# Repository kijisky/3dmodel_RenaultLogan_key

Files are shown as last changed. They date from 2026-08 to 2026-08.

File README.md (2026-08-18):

# Renault Logan key — parametric CAD model

A clean, printable **two-piece (clamshell) key head** for a Renault / Dacia
Logan, built **from scratch** as a parametric B-rep model in
[CadQuery](https://cadquery.readthedocs.io/) (OpenCASCADE kernel). Editing the
parameters at the top of the script reflows the whole part and re-exports
print-ready STLs.

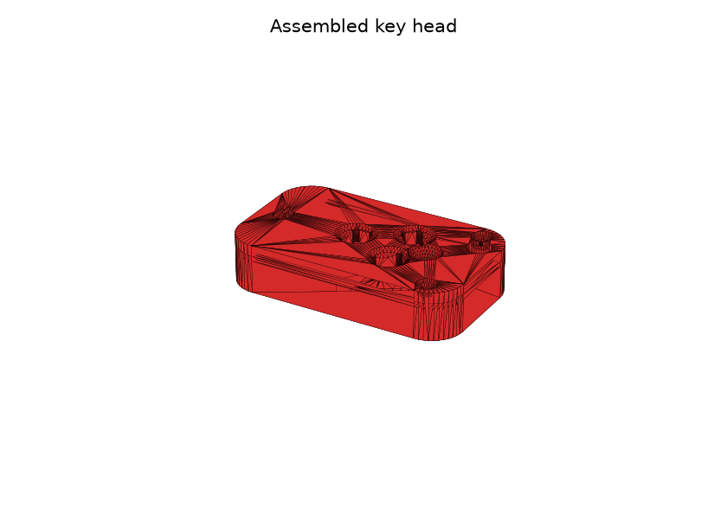
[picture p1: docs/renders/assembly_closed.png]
assembled
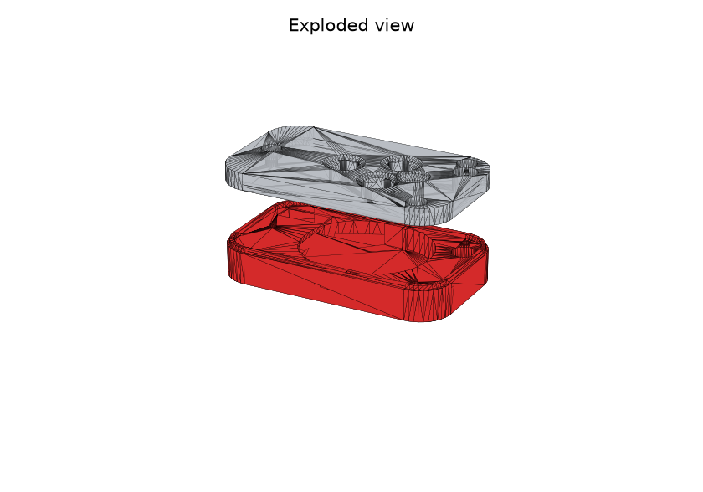
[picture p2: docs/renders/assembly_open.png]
exploded
|  |  |
|---|---|
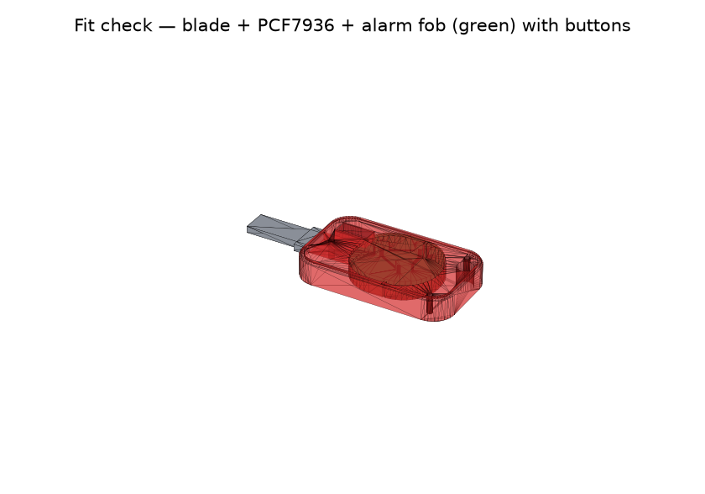
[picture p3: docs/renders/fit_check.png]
fit check
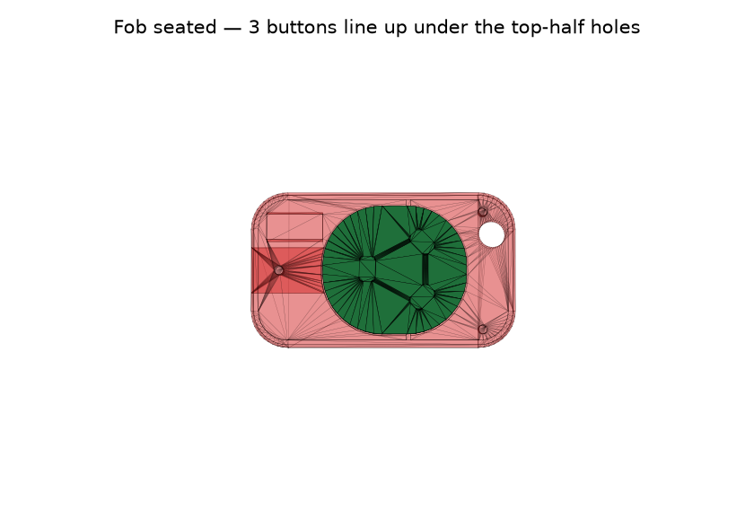
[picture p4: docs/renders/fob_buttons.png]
fob + buttons
|  |  |

> The gray blade, dark chip and green fob in the *fit-check* views are
> **reference geometry only** — they are not part of any printed STL.

Head envelope ≈ **58 × 34 × 12 mm** (auto-sized around the fob, with extra rear
body for the keyring hole). The parting plane is NOT at the mid-height: the
**bottom is thicker, the top (lid) thinner** (`split_ratio`, default 65/35), so
most of the fob and all of the blade/chip retention features sit in the
sturdier half.

## What it holds

1. **Alarm-remote fob** — a round PCB **31.5 × 28 mm, ~7 mm thick, 3 buttons on
   one face** — drops into a rounded **cavity** that fills the middle and rear
   of the head. **Retainer ribs** on the cavity walls grip its edge so it can't
   rattle or spin. Three **rectangular button openings** through the **top** half
   sit over the buttons — each opening is **rotated** (radial from the fob
   centre by default, matching the angled button layout seen on the board) so
   the caps drop in squarely; they're pressed with the lid closed. Insert the
   fob with the shell open, then close the lid.

2. **Blade inserts from the front, like the OEM key, and holds without the
   second half.** The flat metal **tang** slides into a slot in the solid front
   of the **bottom** half; the wider **shoulder** butts the front face as the
   depth stop. Floor + a thin **cap** + side walls capture the tang, and a
   **bolt** through the tang's factory hole locks pull-out (and clamps the two
   halves at the front). The slot runs **through into the fob cavity** (10 mm
   wide), so it is a passage — print supports push straight out into the
   interior instead of being trapped in a blind pocket.

3. **Immobilizer** — the **PCF7936 / "ID46"** transponder sits in a small nest
   in the solid front, right next to the blade, molded **entirely into the
   bottom half**. The nest is full width down low, then **narrows into an
   overhanging snap lip** just below the parting plane: press the chip down
   past the lip (the thin wall flexes briefly) and it springs back over the
   chip — so the chip is **captive in the bottom half alone**, even with the
   top half off. A hold-down pad on the lid adds a second retention layer once
   the key is closed.

4. **Keyring hole** — a plain hole through the extra solid body behind the fob
   (the body is simply longer; no protruding loop). Two back-corner assembly
   screws and an alignment lip/groove close the clamshell.

Because the enlarged front of the head is solid, the blade dock / chip nest /
keyring / bolt are just pockets cut into it — no separate printed bosses.

## Files

```
cad/renault_logan_key.py             the parametric model (edit this — CadQuery)
cad/renault_logan_key_freecad.FCMacro same model as a LIVE FreeCAD parametric object (edit in the GUI)
cad/render_previews.py               regenerates docs/renders/*.png from the STLs
export/bottom_shell.stl              print-ready, flat-side down          (+ .step)
export/top_shell.stl                 print-ready, flat-side down          (+ .step)
export/key_assembled.stl             both halves fused (visual check)     (+ .step)
docs/renders/*.png                   preview images
requirements.txt                     cadquery + render deps
```

Both shell STLs are clean, watertight 2-manifold solids (verified: 0 boundary
edges, 0 non-manifold junctions) and print **flat-side down with no supports**.

## How the blade is held (cross-sections)

```
 side view (Y=0)                       top view (blade height)
 +--------- cap -----------+           front face
 |####  +- tang slot ------|--> into    |  +- 10 mm slot ---------|--> fob
 |####  |   BLADE ---->    | fob cavity  |  |  (through)          | cavity
 |#### bolt  +------------ |             |  +--------------------- |
 |####  # solid / thread # |  shoulder --+<-- butts the front face (depth stop)
 +-- floor ----------------+           bolt hole (o)  through the tang
```

Front insertion: the tang slides in until the **shoulder hits the front
face**. The **bolt** drops through the tang's hole into the solid front and
locks it against pulling back out.

## Build / export

```bash
pip install -r requirements.txt

# export the three STLs into export/
python3 cad/renault_logan_key.py

# also write STEP files (for editing in other CAD)
python3 cad/renault_logan_key.py --step

# regenerate the preview PNGs
python3 cad/render_previews.py
```

## Opening / editing in FreeCAD

Two options depending on what you need:

- **Just want the geometry in FreeCAD?** Import `export/*.step` (File → Import)
  — exact geometry, one click, but a static shape (no parameters, no tree).
- **Want to tweak dimensions directly in FreeCAD's own GUI, no code editing?**
  Run `cad/renault_logan_key_freecad.FCMacro`:
  ```bash
  freecadcmd cad/renault_logan_key_freecad.FCMacro      # headless, no GUI needed
  # or, inside FreeCAD: Macro -> Macros... -> Execute -> browse to the file
  ```
  This builds a **live parametric model** using FreeCAD's own scripted-object
  mechanism (`Part::FeaturePython`), not just a one-shot static shape:

  - A **`KeyParameters`** object appears in the model tree holding every
    dimension (head size, blade, fob, buttons, immobilizer, keyring, screws,
    fit) as an ordinary FreeCAD Property, grouped in the Property panel.
  - **`BottomShell`**, **`TopShell`**, **`KeyAssembled`** (plus reference
    `RefBlade` / `RefChip` / `RefFob`) all read from `KeyParameters` and
    rebuild their shape on recompute.

  **To change something:** select `KeyParameters` in the tree, edit any value
  in the Property panel (e.g. `head_length`, `chip_snap_overlap`,
  `button_x`/`button_y`), then **recompute** (the refresh-arrows toolbar
  button, or F5) — `BottomShell`/`TopShell`/`KeyAssembled` all update
  automatically. Export whichever one you want via File → Export (STL for
  printing, STEP for elsewhere) once you're happy with it. No code, no
  re-running the macro needed for ordinary tweaks.

  Re-running the macro later (e.g. in a fresh FreeCAD session after reopening
  the file) is safe — it reuses the existing objects and just re-attaches
  their live-recompute behaviour, **without discarding any values you already
  edited**; it only fills in the defaults below the very first time.

  ### On this port's verification
  This dev environment has no FreeCAD install, so the macro could not be run
  inside real FreeCAD. It **was** verified by executing the identical
  Part-API call sequence (same `Part.makeBox` / `makeCylinder` / `fuse` /
  `cut` / `makeFillet` calls) directly against the OpenCASCADE kernel that
  FreeCAD's own `Part` module wraps, including the full live-editing cycle:
  build → edit a property → confirm the shape is still the OLD size →
  recompute → confirm it changed to the NEW size → re-run the macro →
  confirm the edited value survived and no objects were duplicated. Bounding
  boxes and **exact BREP volumes matched the CadQuery model to 0.1 mm³**, and
  every resulting mesh was watertight (0 boundary edges, 0 non-manifold
  junctions) both at the default dimensions and after editing several
  parameters at once. The one thing that couldn't be exercised from outside
  FreeCAD is the literal `FreeCAD`/`Part` module surface and the Property
  panel UI itself (`addProperty`'s exact runtime behaviour, `.FCStd`
  save/reload of the scripted Proxy) — if something looks off there on first
  run, the geometry underneath it is already proven correct; it would be a
  FreeCAD-API detail to adjust, not a design problem.

## IMPORTANT — measure your own blank before printing

There is no verified physical Logan blank behind these numbers, so the
blade/shoulder dimensions are **estimates** for the Renault/Dacia
**NE73 / VA2 / VAC102** blade family and the PCF7936 nest is sized from the
common aftermarket "ID46" carrier. Clones vary. Put calipers on your actual
parts and update the `KeyParams` block at the top of
`cad/renault_logan_key.py`:

```python
fob_length, fob_width, fob_body_thickness    # your alarm fob PCB (31.5 x 28 x 7)
fob_button_height                            # how far the buttons stand proud
button_positions                             # (x, y) of each button in FOB-LOCAL mm
button_slot_l, button_slot_w                 # rectangular opening size  << CHECK THESE
button_radial, button_angles                 # opening rotation — see below
indicator_x, indicator_y                     # blink-LED dish centre, FOB-LOCAL mm  << CHECK THESE
blade_width, blade_thickness, blade_insert   # the tang that enters the head
shoulder_width, shoulder_length              # the external stop (width > blade_width)
bolt_offset                                  # must line up with the hole in YOUR tang
chip_length, chip_width, chip_thickness      # your PCF7936 carrier
chip_snap_lip_height, chip_snap_overlap      # how strong the chip's snap retention is
split_ratio                                  # bottom/top thickness split (0.5 = even)
clearance                                    # loosen/tighten every pocket at once
```

`button_positions` came from the supplied photos and **must be verified** against
your board — they set where the top-half holes land. Each opening is rotated by
`button_radial` (default: auto — points radially away from the fob centre,
matching the angled layout in the photos); set `button_radial = False` and fill
in `button_angles` (degrees per button) if you need exact angles instead. The
head envelope (`head_length/width/height`) is chosen to wrap the fob; if you
change the fob size, bump these to keep ~2 mm of wall around it.

`indicator_x`/`indicator_y` place the dished-down spot over the fob's blink
LED (between the two side buttons by default) — verify against your board.
It isn't a hole: `indicator_dimple_depth` just thins the ceiling there far
more than a button's finger dish (`button_dimple_depth`) so the blink shows
through; tune `indicator_dimple_depth` against your filament's actual
translucency (thinner = brighter blink but more fragile).

**Chip snap-fit tuning:** `chip_snap_overlap` (default 0.4 mm per side) is the
interference the chip must be pressed past — increase it for a firmer retention
if the chip falls out too easily, decrease it (or shrink `chip_snap_lip_height`)
if it's too hard to press in or the thin lip wall cracks when printed in your
material.

## Printing notes

- Print both halves **flat-side down** as exported — each is a simple open
  tray, no supports.
- Hardware: 2 back-corner self-tapping screws + 1 blade bolt at the front
  (which also clamps the halves). Defaults sized for **M2.5 self-tap**:
  ~2.0 mm pilot in the bottom, 2.7 mm clearance + counterbore in the top —
  change the `asm_*` / `blade_*` parameters for your screws.
- Drop the **fob** into its cavity and **press the chip down past its snap lip**
  into its nest in the printed **bottom** half (it should click in and stay put
  even before the lid goes on), check the blade tang slides in and the buttons
  line up under the top-half holes, then close the lid. Adjust `clearance` /
  `fob_clearance` if anything is too tight or too loose, `chip_snap_overlap` if
  the chip is too hard/easy to seat, and confirm `bolt_offset` lines up with the
  hole in your tang.

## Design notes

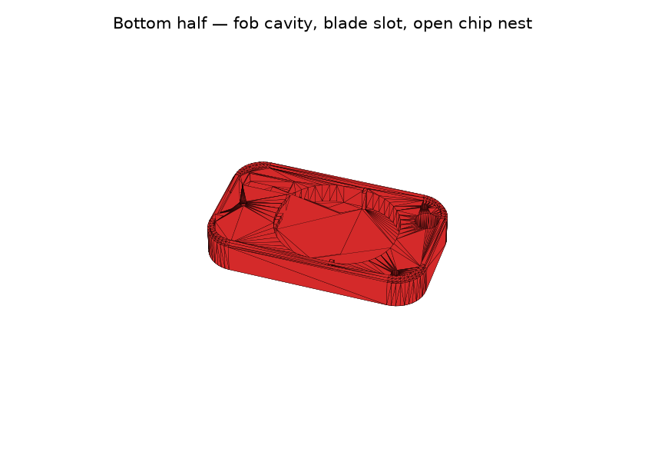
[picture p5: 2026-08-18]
docs/renders/bottom_shell.png

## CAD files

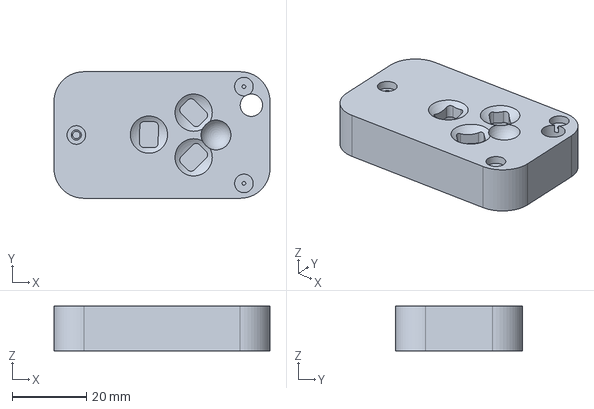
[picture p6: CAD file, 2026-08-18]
export/key_assembled.step
58.0 x 34.0 x 12.0 mm

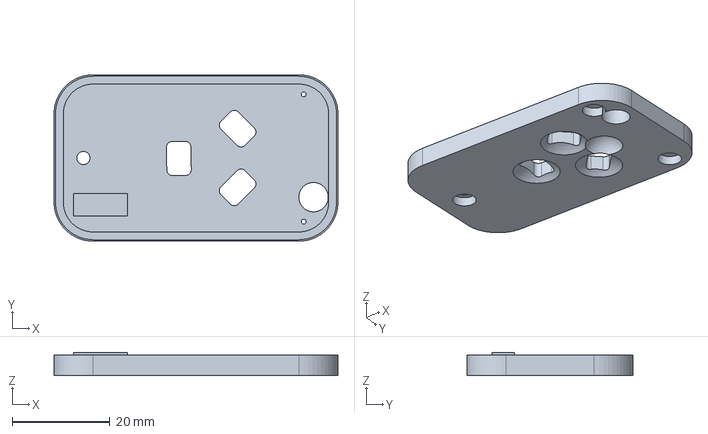
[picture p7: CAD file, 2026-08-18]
export/top_shell.step
58.0 x 34.0 x 4.70 mm

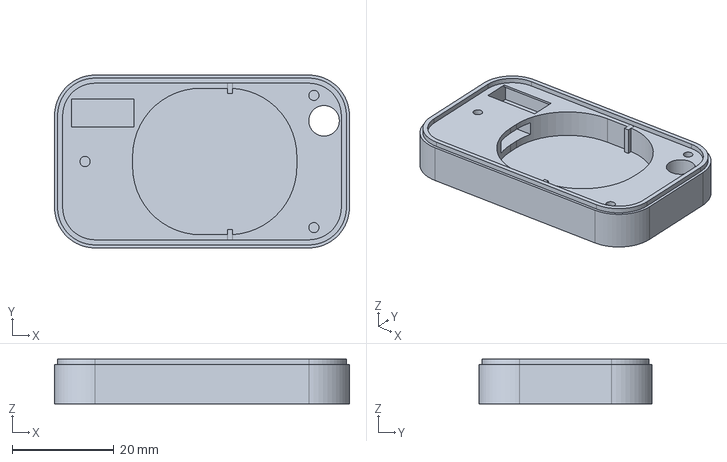
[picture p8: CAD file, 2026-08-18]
export/bottom_shell.step
58.0 x 34.0 x 8.82 mm

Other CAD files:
export/bottom_shell.stl
export/key_assembled.stl
export/top_shell.stl

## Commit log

2026-07-06 Add parametric key shell model (phase 1): blade + immobilizer
    Two-piece OpenSCAD shell that accepts the transplanted Renault Logan
    key blade (with factory shoulder for retention) and an ID46 immobilizer
    transponder capsule. Top/bottom halves are built independently for
    clean 2-manifold STLs, joined with screw bosses and an alignment lip.
    Hollow interior is sized generously to leave room for the phase 2
    Pharaon V16i remote cavity.
    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
    [bottom_shell.stl, renault_logan_key.scad, top_shell.stl]
2026-07-06 Bolt-through blade retention, real PCF7936 nest, fix print orientation
    - Blade is now bolted through its factory shoulder hole into a boss in
    the bottom half (VAC-key style), replacing the friction-fit pin. Also
    fixes the blade/shoulder position, which was on the wrong side of the
    front wall in the reference geometry.
    - Replace the immobilizer channel with an explicit rectangular floor nest
    sized for the PCF7936's actual package (NXP SOT385-1 flat stick, not a
    glass capsule) so it's an obvious, visible feature instead of a hidden
    cylindrical channel.
    - render_mode="top" now reorients the top shell flat-side down (as it
    should be printed) instead of its assembled (lid-up) orient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
    [bottom_shell.stl, renault_logan_key.scad, top_shell.stl]
2026-07-11 New parametric key model (CadQuery): front-insert blade + PCF7936 nest
    Fresh, from-scratch parametric CAD model of the Renault/Dacia Logan key head,
    replacing the previous OpenSCAD model. Built in CadQuery (OpenCASCADE B-rep),
    fully driven by a KeyParams block and exporting watertight print-ready STLs
    (plus STEP).
    - Blade retention like the OEM key: the metal tang slides into a closed slot
    in a solid dock in the bottom half; the wider shoulder butts the front face
    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
    [bottom_shell.step, bottom_shell.stl, key_assembled.step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]
2026-07-11 Add alarm-fob cavity + button holes; enlarge head, chip by the blade
    Reworks the key head into a fob carrier per the measured alarm remote
    (round PCB 31.5 x 28 mm, ~7 mm body, 3 buttons on one face):
    - Rounded fob cavity fills the middle/rear of the head; the fob drops in with
    the shell open. Head auto-sized to wrap it (~50 x 34 x 12 mm).
    - 3 button holes through the TOP half over the fob's buttons (3 mm buttons poke
    through), positions parametric (button_positions, from the photos — verify).
    - Enlarged front of the head is solid, so blade dock / chip nest / keyring /
    bolt are pockets cut into it (no separate bosses). Blade retention unchanged:
    tang into a front slot, shoulder sto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
    [bottom_shell.step, bottom_shell.stl, key_assembled.step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]
2026-07-11 Open the immobilizer nest so the chip can be inserted
    The chip nest was a blind pocket capped by a thin ceiling in the bottom half,
    so the transponder could not be dropped in. Make it OPEN at the parting plane:
    with the shell open the chip drops straight into the nest from above, and the
    closed lid caps it. Also right-size the default carrier to a realistic PCF7936
    (~13 x 6 x 2.5 mm) and reposition it beside the blade so it clears the round
    fob cavity. Nest floor/height are now derived from chip_thickness.
    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
    [bottom_shell.step, bottom_shell.stl, key_assembled.step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]
2026-07-11 Through blade slot (10 mm), keyring eyelet, longer rear anchor
    - Blade slot now runs THROUGH the solid front into the fob cavity (no blind
    pocket), so print supports push straight out into the interior. Slot width is
    its own parameter, widened to 10 mm for an easy fit; the shoulder still sets
    insertion depth so no internal back stop is needed.
    - Added a rounded keyring EYELET protruding from the back, with a ring hole,
    anchored in a solid block behind the fob; removed the old front-corner keyring
    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
    [bottom_shell.step, bottom_shell.stl, key_assembled.step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]
2026-07-11 Keyring hole in a longer body instead of a protruding eyelet
    Drop the protruding loop; make the body simply longer (58 mm) and put a plain
    Z keyring hole through the extra solid rear section behind the fob. Back screws
    moved to the new rear corners. STLs remain watertight 2-manifold.
    Claude-Session: https://claude.ai/code/session_01XLwKs4e3GMSohgKJb6rSoR
    [bottom_shell.step, bottom_shell.stl, key_assembled.step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]
2026-07-11 Fob retainer ribs, rectangular button openings, captive chip nest
    Refinements after a test print:
    - Fob no longer rattles: 6 crush ribs on the cavity walls grip its edge and
    stop it spinning; cavity clearance tightened to 0.4 mm.
    - Button holes are now RECTANGULAR openings the caps drop into (generous size
    so a small position error still clears), instead of round holes.
    - Immobilizer can no longer fall out: the nest is fully walled (chip resized/
    repositioned to leave real walls front and back) and a hold-down pad on the
    lid presses the chip so it is trapped once the key is closed.
    button_positions still come from the photos — set exact values from your board
    if the caps don't lin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
    [bottom_shell.step, bottom_shell.stl, key_assembled.step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]
2026-07-12 Thicker bottom/thinner top, captive chip snap-lip, angled buttons, FreeCAD macro
    Four refinements after the printed test:
    - split_ratio parameter (default 0.65) makes the bottom half thicker and the
    top (lid) thinner, so more of the fob body and all the retention features
    sit in the sturdier half. Bottom now 7.8mm / top 4.2mm (was 6/6).
    - Immobilizer nest reworked so the chip is captive in the BOTTOM HALF ALONE:
    the pocket narrows into an overhanging snap lip just below the parting
    plane (chip_snap_lip_height / chip_snap_overlap) -- press the chip past the
    lip and it's trapped even with the top half off. The lid's hold-down pad is
    kept as a second layer once closed.
    - Button ope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
    [bottom_shell.step, bottom_shell.stl, key_assembled.step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]
2026-07-12 Turn the FreeCAD macro into a live, GUI-editable parametric model
    Replace the static "build once and export" FreeCAD port with real FreeCAD
    scripted parametric objects (Part::FeaturePython):
    - A single "KeyParameters" object holds every dimension (head/blade/fob/
    buttons/immobilizer/keyring/screws/fit) as an ordinary FreeCAD Property,
    grouped in the Property panel.
    - BottomShell / TopShell / KeyAssembled (+ RefBlade/RefChip/RefFob) each link
    to KeyParameters and rebuild their Shape on recompute via a shared
    ShapeProxy, so editing a value in the Property panel and hitting Recompute
    updates the whole model -- no code editing required.
    - Builder identity is stored as a plain FreeCAD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
2026-07-12 Fob retainer ribs: one per side, thinner, shifted back; keyring off-centre
    Fob retainer ribs (both CadQuery and FreeCAD-macro versions, kept in sync):
    - One rib per long (Y) cavity wall instead of three (was dx in -10/0/10) --
    removes the dead fob_retainer_dia leftover from an earlier cylindrical-rib
    design and replaces it with the parameters actually used:
    - fob_retainer_thickness: rib length along the wall, 3.0mm -> 1.0mm.
    - fob_retainer_dx: new parameter, +3mm from the fob centre (toward the back/
    fob cavity, away from the blade).
    Keyring hole: keyring_y 0.0 -> 8.0mm, off-centre toward one edge instead of
    centred on the head's Y axis.
    Verified: CadQuery STLs stay watertight (0 hol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
    [bottom_shell.step, bottom_shell.stl, key_assembled.step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]
2026-08-16 Recover manual tuning: button layout/rotation, fob grip, chip/screw sizing
    These were made as local edits to an older, pre-live-parametric copy of
    the FreeCAD macro and never landed in git, so both the CadQuery model
    and the FreeCAD macro had drifted back to stale defaults. Ported forward
    into both (kept in sync per file header convention):
    - button_positions moved in and re-rotated (+90 deg) to match the fob's
    actual angled button layout
    - fob_retainer_grip 0.2 -> 0.6 (more interference on the retention ribs)
    - chip_thickness 2.5 -> 1.5 (matches the real PCF7936 carrier)
    - asm_clear_dia 2.7 -> 1.0 (smaller assembly-screw shank clearance)
    Regenerated export/*.stl and export/*.step from t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
    [bottom_shell.step, bottom_shell.stl, key_assembled.step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]
2026-08-16 Remove top-half fob cavity cut: fixes rattling fob
    Cutting the fob pocket into both halves left too much total depth and
    the fob rattled in an early print. Leaving the top solid over the fob
    region (bottom pocket alone holds it) is what the earlier manual edit
    was doing — restoring that here in both the CadQuery model and the
    FreeCAD macro.
    Regenerated export/*.stl and export/*.step; all three solids still
    build as valid, watertight bodies.
    Claude-Session: https://claude.ai/code/session_01KrRb33ChrUo1wdXoBrJQBv
    [bottom_shell.step, key_assembled.step, key_assembled.stl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]
2026-08-16 Deepen the immobilizer chip nest: chip_thickness 1.5 -> 3.0mm
    The nest was too shallow in practice. chip_floor = split_z -
    chip_thickness - 0.6, so this pushes the floor down by 1.5mm (4.2mm
    now vs 2.5mm minimum allowed by wall+0.3, still well clear) without
    moving the chip's top surface, snap lip, or hold-down pad -- those are
    all anchored to split_z, not to the floor, so the snap-fit retention
    mechanics are unaffected; only the pocket gets deeper.
    Verified: bottom_shell/top_shell/key_assembled still build valid and
    watertight, chip_reference (now 3mm) sits fully within the deepened
    pocket (z 4.2-7.2), and there's no interference with the blade channel
    or assembly-screw holes (they don't s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
    [bottom_shell.step, bottom_shell.stl, key_assembled.step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]
2026-08-16 Add finger dishes around the fob buttons for a comfortable press
    The button openings were flat slots through a rigid ceiling -- fine
    mechanically, uncomfortable to press. Each opening now gets a shallow
    spherical-cap dish (button_dimple_dia=10mm rim, button_dimple_depth=
    1.2mm at centre) cut into the outer face, so a fingertip settles onto
    the button instead of poking a flat edge. Toggle with button_dimple;
    new button_dimple_cut() uses the standard sagitta formula to size the
    cutting sphere from the requested rim diameter/depth.
    Caught and fixed a real bug along the way: the first version of
    ball() returned a raw cq.Solid, and Workplane.cut() silently no-ops
    on that (confirmed directly: box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
    [bottom_shell.step, key_assembled.step, key_assembled.stl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]
2026-08-17 Thin the ceiling over the blink LED, deepen the button finger dishes
    The fob's status LED sits between the two side (open/close) buttons,
    but the ceiling there was full thickness (4.2mm) and opaque -- no
    button dimple, no window, so the blink never showed through the
    closed lid. Added indicator_dimple_cut(), the same sagitta-based
    spherical-cap dish as button_dimple_cut() but with no hole underneath
    (it's not pressed): indicator_dimple_depth=3.2mm leaves ~1.0mm of
    ceiling at its centre, a third of what a button's dish leaves
    (4.2 - 1.2 = 3.0mm at the pre-existing 1.2mm depth) -- verified by
    probing the built solid at the indicator centre (1.002mm remaining).
    Position (indicator_x=12, indicat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
    [bottom_shell.step, key_assembled.step, key_assembled.stl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]
